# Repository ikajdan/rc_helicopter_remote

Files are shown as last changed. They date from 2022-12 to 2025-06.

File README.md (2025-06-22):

# RC Helicopter Remote

## Overview

This project is a custom PCB-based remote controller for an RC helicopter, built around the STM32L452RET6 microcontroller. It interfaces with two joysticks, four buttons, and two potentiometers to capture user input and transmits control data wirelessly via the NRF24L01 module to the helicopter's mainboard.

It complements the [Mainboard PCB](https://github.com/ikajdan/rc_helicopter_mainboard) and is developed in parallel with it as part of the same system.

## Features

The board features an STM32L452RET6 microcontroller, powered by a Li-Ion battery regulated to 3.3 V. It includes a 16 MHz crystal oscillator for accurate timing and clocking. Input devices such as two joysticks (X, Y, S), multiple buttons (SW1–SW4), and two analog potentiometers are connected directly to GPIO pins. Wireless communication is handled by the NRF24L01 module via SPI. Several status LEDs provide user feedback.

## PCB Design

This is a 2-layer compact PCB designed for handheld use, with easy access to controls and routing for digital and analog signals.

| Front View | Back View |
|---|---|
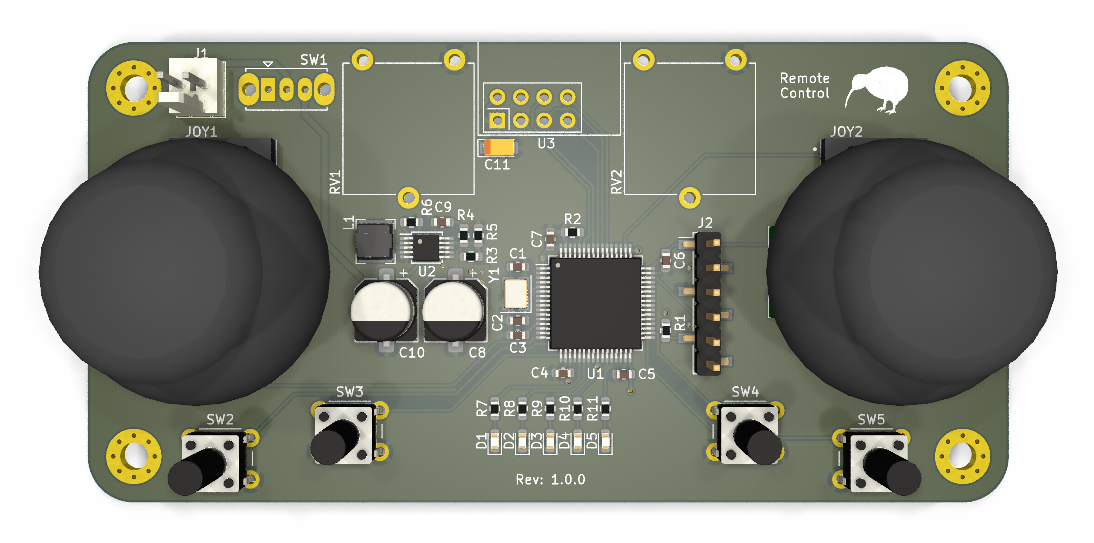
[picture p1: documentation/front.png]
PCB Front
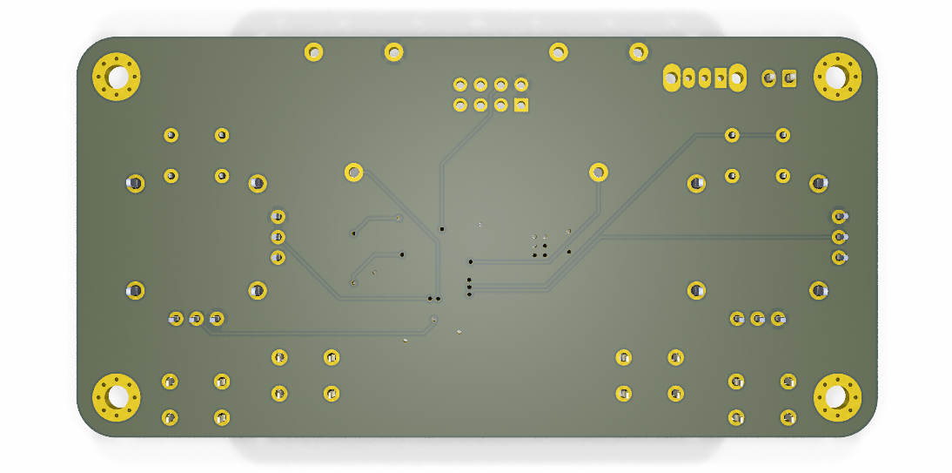
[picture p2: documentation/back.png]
PCB Back
|  |  |

## Power Supply

The power supply uses an LTC3440 buck-boost converter to step the battery voltage down to 3.3 V. Key components include a 10 µH inductor, 22 µF output capacitor, and feedback resistors (R3 = 340 kΩ, R5 = 200 kΩ, R4 = 15 kΩ) to set the output voltage. The converter is configured for efficient operation across a wide input range and includes filtering components for stability. A power switch and 10 µF input capacitor (C10) are included for basic input protection and noise reduction.

## License

This project is licensed under the [CERN Open Hardware Licence Version 2 - Permissive (CERN-OHL-P)](https://ohwr.org/cern_ohl_p_v2.txt).
You are free to use, modify, and distribute this design, provided you retain notices and disclaimers as specified in the license terms. See the [LICENSE](LICENSE.md) file for full details.

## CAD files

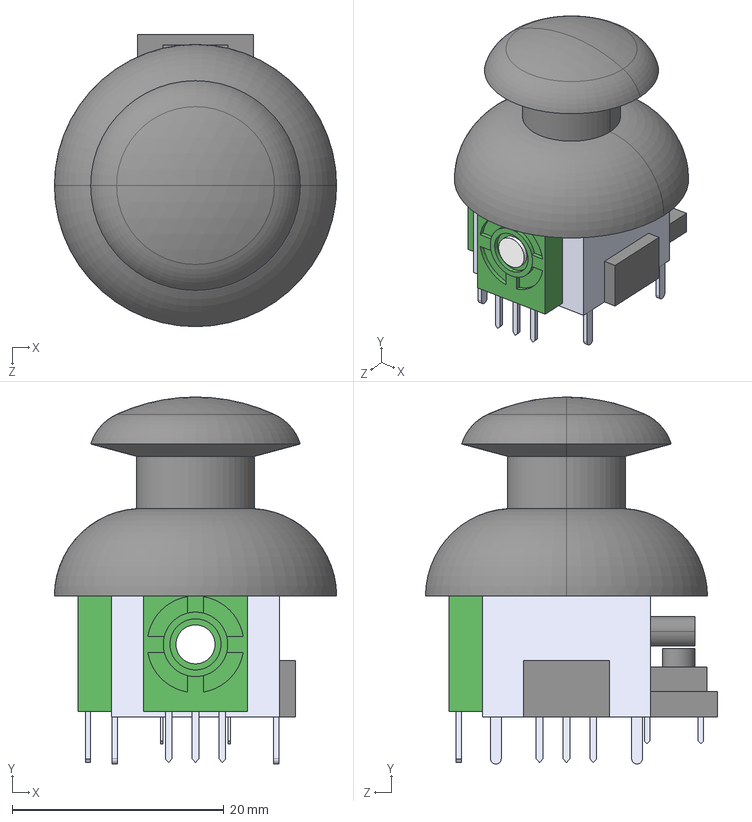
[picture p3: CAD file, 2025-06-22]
hardware/models/COM-09032.step
26.7 x 34.7 x 27.6 mm

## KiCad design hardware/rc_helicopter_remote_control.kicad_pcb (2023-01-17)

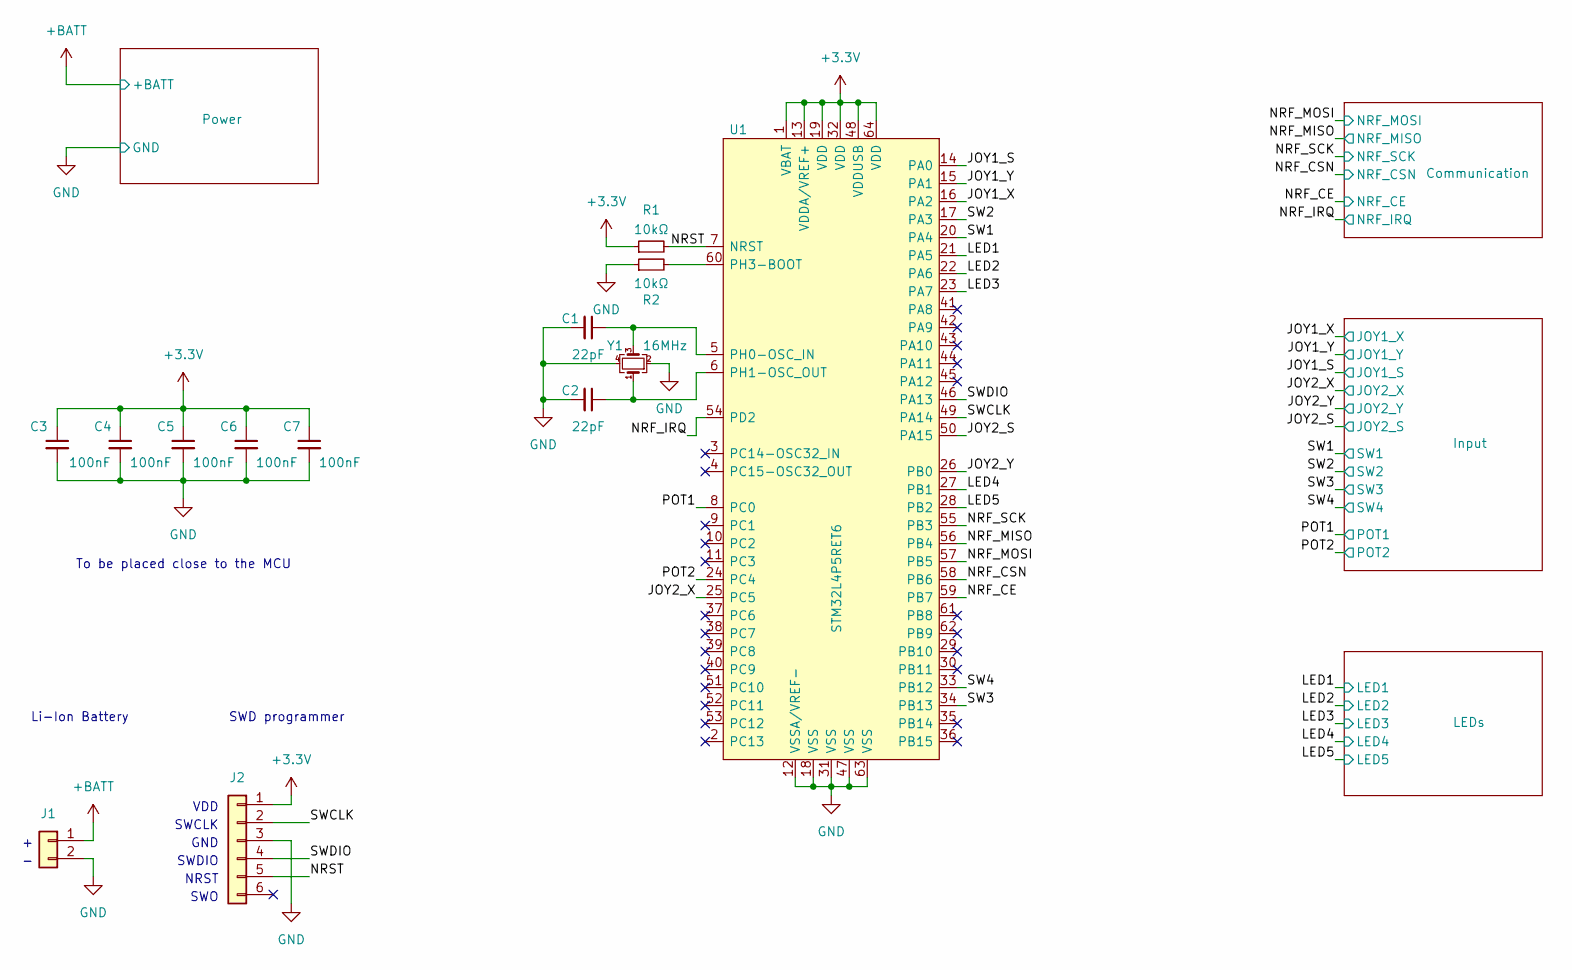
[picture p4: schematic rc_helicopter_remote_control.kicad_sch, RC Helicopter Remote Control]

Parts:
C1, C2: 22pF; C_0603_1608Metric
C3, C4, C5, C6, C7: 100nF; C_0603_1608Metric
J1: Battery Pack; Molex_KK-254_AE-6410-02A_1x02_P2.54mm_Vertical
J2: SWD; PinHeader_1x06_P2.54mm_Vertical_SMD_Pin1Left
R1, R2: 10kΩ; R_0603_1608Metric
U1: STM32L4P5RET6; LQFP-64_10x10mm_P0.5mm
Y1: 16MHz; Crystal_SMD_3225-4Pin_3.2x2.5mm

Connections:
+3.3V: C3.1, C4.1, C5.1, C6.1, C7.1, J2.1, R1.1, U1.1 (VBAT), U1.13 (VDDA/VREF+), U1.19 (VDD), U1.32 (VDD), U1.48 (VDDUSB), U1.64 (VDD); also elsewhere on the board
+BATT: J1.1; also elsewhere on the board
/JOY1_S: U1.14 (PA0); also elsewhere on the board
/JOY1_X: U1.16 (PA2); also elsewhere on the board
/JOY1_Y: U1.15 (PA1); also elsewhere on the board
/JOY2_S: U1.50 (PA15); also elsewhere on the board
/JOY2_X: U1.25 (PC5); also elsewhere on the board
/JOY2_Y: U1.26 (PB0); also elsewhere on the board
/LED1: U1.21 (PA5); also elsewhere on the board
/LED2: U1.22 (PA6); also elsewhere on the board
/LED3: U1.23 (PA7); also elsewhere on the board
/LED4: U1.27 (PB1); also elsewhere on the board
/LED5: U1.28 (PB2); also elsewhere on the board
/NRF_CE: U1.59 (PB7); also elsewhere on the board
/NRF_CSN: U1.58 (PB6); also elsewhere on the board
/NRF_IRQ: U1.54 (PD2); also elsewhere on the board
/NRF_MISO: U1.56 (PB4); also elsewhere on the board
/NRF_MOSI: U1.57 (PB5); also elsewhere on the board
/NRF_SCK: U1.55 (PB3); also elsewhere on the board
/NRST: J2.5, R1.2, U1.7 (NRST)
/POT1: U1.8 (PC0); also elsewhere on the board
/POT2: U1.24 (PC4); also elsewhere on the board
/SW1: U1.20 (PA4); also elsewhere on the board
/SW2: U1.17 (PA3); also elsewhere on the board
/SW3: U1.34 (PB13); also elsewhere on the board
/SW4: U1.33 (PB12); also elsewhere on the board
/SWCLK: J2.2, U1.49 (PA14)
/SWDIO: J2.4, U1.46 (PA13)
GND: C1.2, C2.2, C3.2, C4.2, C5.2, C6.2, C7.2, J1.2, J2.3, R2.1, U1.12 (VSSA/VREF-), U1.18 (VSS), U1.31 (VSS), U1.47 (VSS), U1.63 (VSS), Y1.2, Y1.4; also elsewhere on the board
unnamed: C1.1, U1.5 (PH0-OSC_IN), Y1.3
unnamed: C2.1, U1.6 (PH1-OSC_OUT), Y1.1
unnamed: R2.2, U1.60 (PH3-BOOT)

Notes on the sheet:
Li-Ion Battery
SWDIO
To be placed close to the MCU
NRST
VDD
SWD programmer
GND
SWCLK
SWO

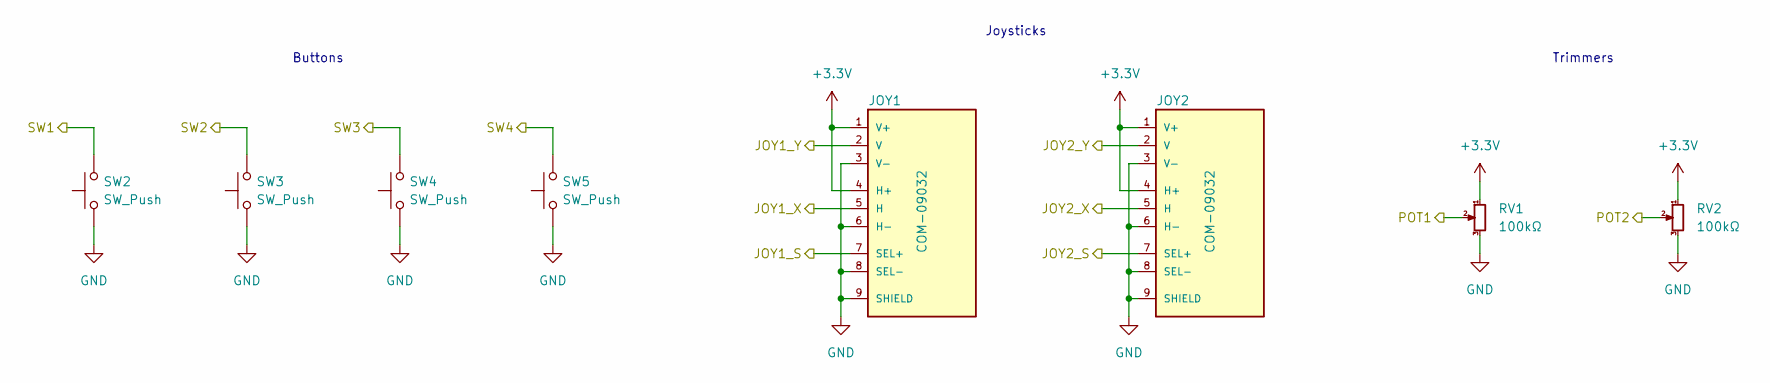
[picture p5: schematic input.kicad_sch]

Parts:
JOY1, JOY2: COM-09032; XDCR_COM-09032; PARTREV N/A
RV1, RV2: 100kΩ; Potentiometer_ACP_CA14V-15_Vertical
SW2, SW3, SW4, SW5: SW_Push; SW_PUSH_6mm_H13mm

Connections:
+3.3V: JOY1.1 (V+), JOY1.4 (H+), JOY2.1 (V+), JOY2.4 (H+), RV1.1, RV2.1; also elsewhere on the board
/JOY1_S: JOY1.7 (SEL+); also elsewhere on the board
/JOY1_X: JOY1.5 (H); also elsewhere on the board
/JOY1_Y: JOY1.2 (V); also elsewhere on the board
/JOY2_S: JOY2.7 (SEL+); also elsewhere on the board
/JOY2_X: JOY2.5 (H); also elsewhere on the board
/JOY2_Y: JOY2.2 (V); also elsewhere on the board
/POT1: RV1.2; also elsewhere on the board
/POT2: RV2.2; also elsewhere on the board
/SW1: SW2.1; also elsewhere on the board
/SW2: SW3.1; also elsewhere on the board
/SW3: SW4.1; also elsewhere on the board
/SW4: SW5.1; also elsewhere on the board
GND: JOY1.3 (V-), JOY1.6 (H-), JOY1.8 (SEL-), JOY1.9 (SHIELD), JOY2.3 (V-), JOY2.6 (H-), JOY2.8 (SEL-), JOY2.9 (SHIELD), RV1.3, RV2.3, SW2.2, SW3.2, SW4.2, SW5.2; also elsewhere on the board

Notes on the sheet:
Trimmers
Joysticks
Buttons

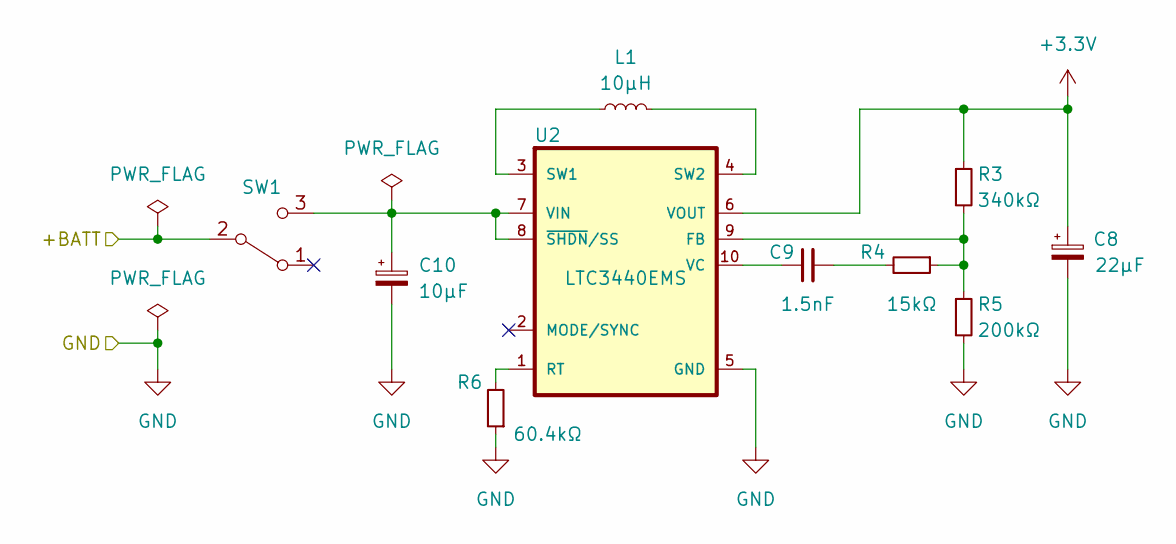
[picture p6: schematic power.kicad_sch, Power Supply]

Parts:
C8: 22μF; CP_Elec_6.3x5.4
C9: 1.5nF; C_0603_1608Metric
C10: 10μF; CP_Elec_6.3x5.4
L1: 10μH; L_Bourns-SRN4018
R3: 340kΩ; R_0603_1608Metric
R4: 15kΩ; R_0603_1608Metric
R5: 200kΩ; R_0603_1608Metric
R6: 60.4kΩ; R_0603_1608Metric
SW1: SW_SPST; SW_Slide_1P2T_CK_OS102011MS2Q
U2: LTC3440EMS; MSOP-10_3x3mm_P0.5mm; MPN LTC3440EMS#PBF

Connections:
+3.3V: C8.1, R3.1, U2.6 (VOUT); also elsewhere on the board
+BATT: SW1.2 (B); also elsewhere on the board
GND: C8.2, C10.2, R5.2, R6.1, U2.5 (GND); also elsewhere on the board
unnamed: C9.1, U2.10 (VC)
unnamed: C9.2, R4.2
unnamed: C10.1, SW1.3 (C), U2.7 (VIN), U2.8 (~SHDN/SS)
unnamed: L1.1, U2.3 (SW1)
unnamed: L1.2, U2.4 (SW2)
unnamed: R3.2, R4.1, R5.1, U2.9 (FB)
unnamed: R6.2, U2.1 (RT)

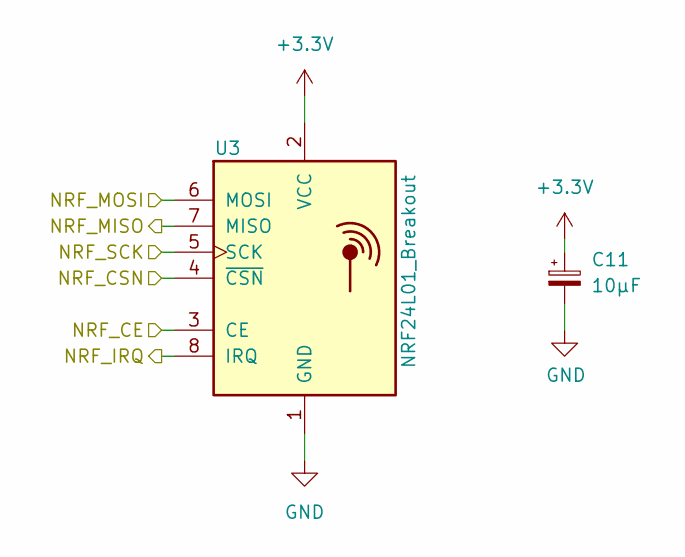
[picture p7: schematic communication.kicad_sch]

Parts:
C11: 10μF; CP_EIA-3216-10_Kemet-I
U3: NRF24L01_Breakout; nRF24L01_Breakout

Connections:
+3.3V: C11.1, U3.2 (VCC); also elsewhere on the board
/NRF_CE: U3.3 (CE); also elsewhere on the board
/NRF_CSN: U3.4 (~CSN); also elsewhere on the board
/NRF_IRQ: U3.8 (IRQ); also elsewhere on the board
/NRF_MISO: U3.7 (MISO); also elsewhere on the board
/NRF_MOSI: U3.6 (MOSI); also elsewhere on the board
/NRF_SCK: U3.5 (SCK); also elsewhere on the board
GND: C11.2, U3.1 (GND); also elsewhere on the board

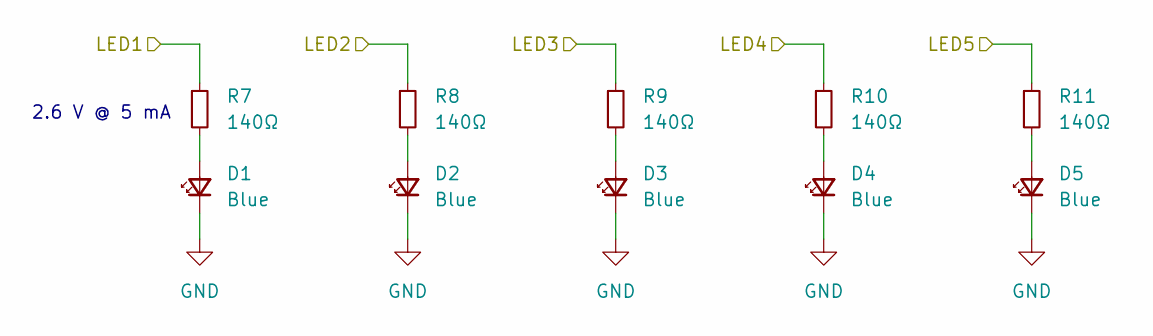
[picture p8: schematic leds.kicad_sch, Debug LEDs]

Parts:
D1, D2, D3, D4, D5: Blue; LED_0603_1608Metric
R7, R8, R9, R10, R11: 140Ω; R_0603_1608Metric

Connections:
/LED1: R7.1; also elsewhere on the board
/LED2: R8.1; also elsewhere on the board
/LED3: R9.1; also elsewhere on the board
/LED4: R10.1; also elsewhere on the board
/LED5: R11.1; also elsewhere on the board
GND: D1.1 (K), D2.1 (K), D3.1 (K), D4.1 (K), D5.1 (K); also elsewhere on the board
unnamed: D1.2 (A), R7.2
unnamed: D2.2 (A), R8.2
unnamed: D3.2 (A), R9.2
unnamed: D4.2 (A), R10.2
unnamed: D5.2 (A), R11.2

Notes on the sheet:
2.6 V @ 5 mA

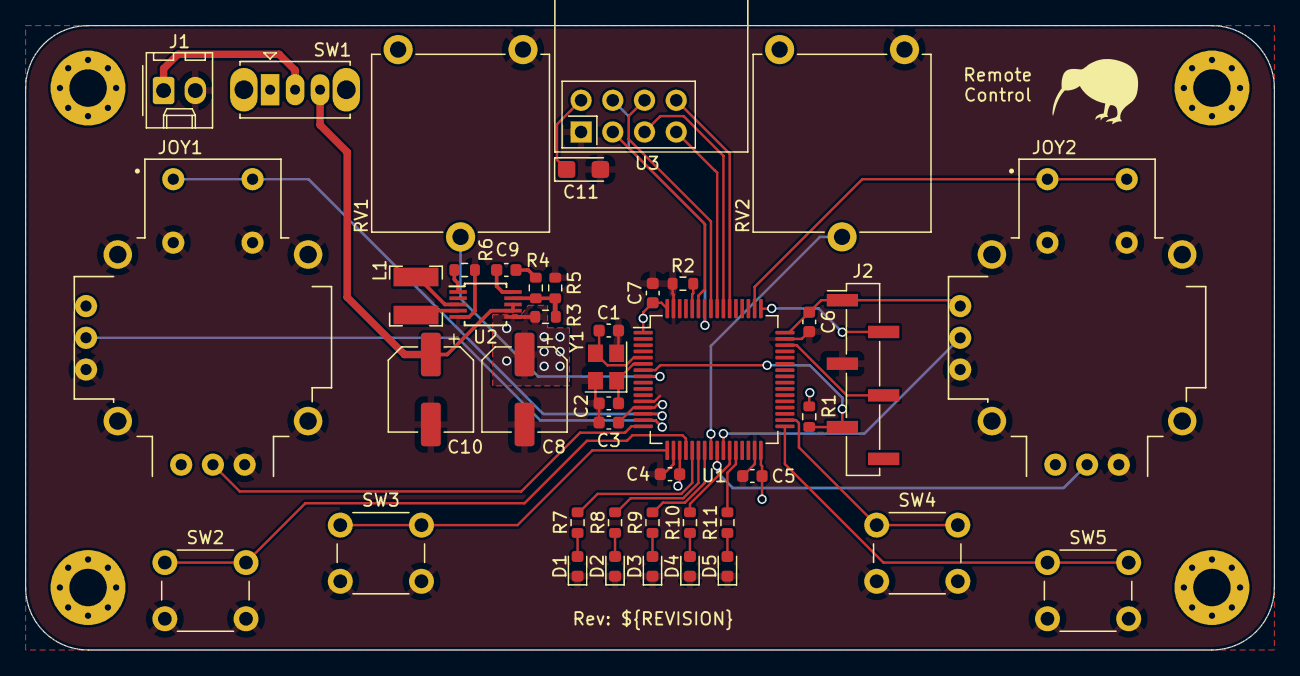
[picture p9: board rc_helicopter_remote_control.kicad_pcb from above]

Board: 2 copper layers, 100.0 x 50.0 mm, 43 parts (0 on the bottom side), 44 nets.

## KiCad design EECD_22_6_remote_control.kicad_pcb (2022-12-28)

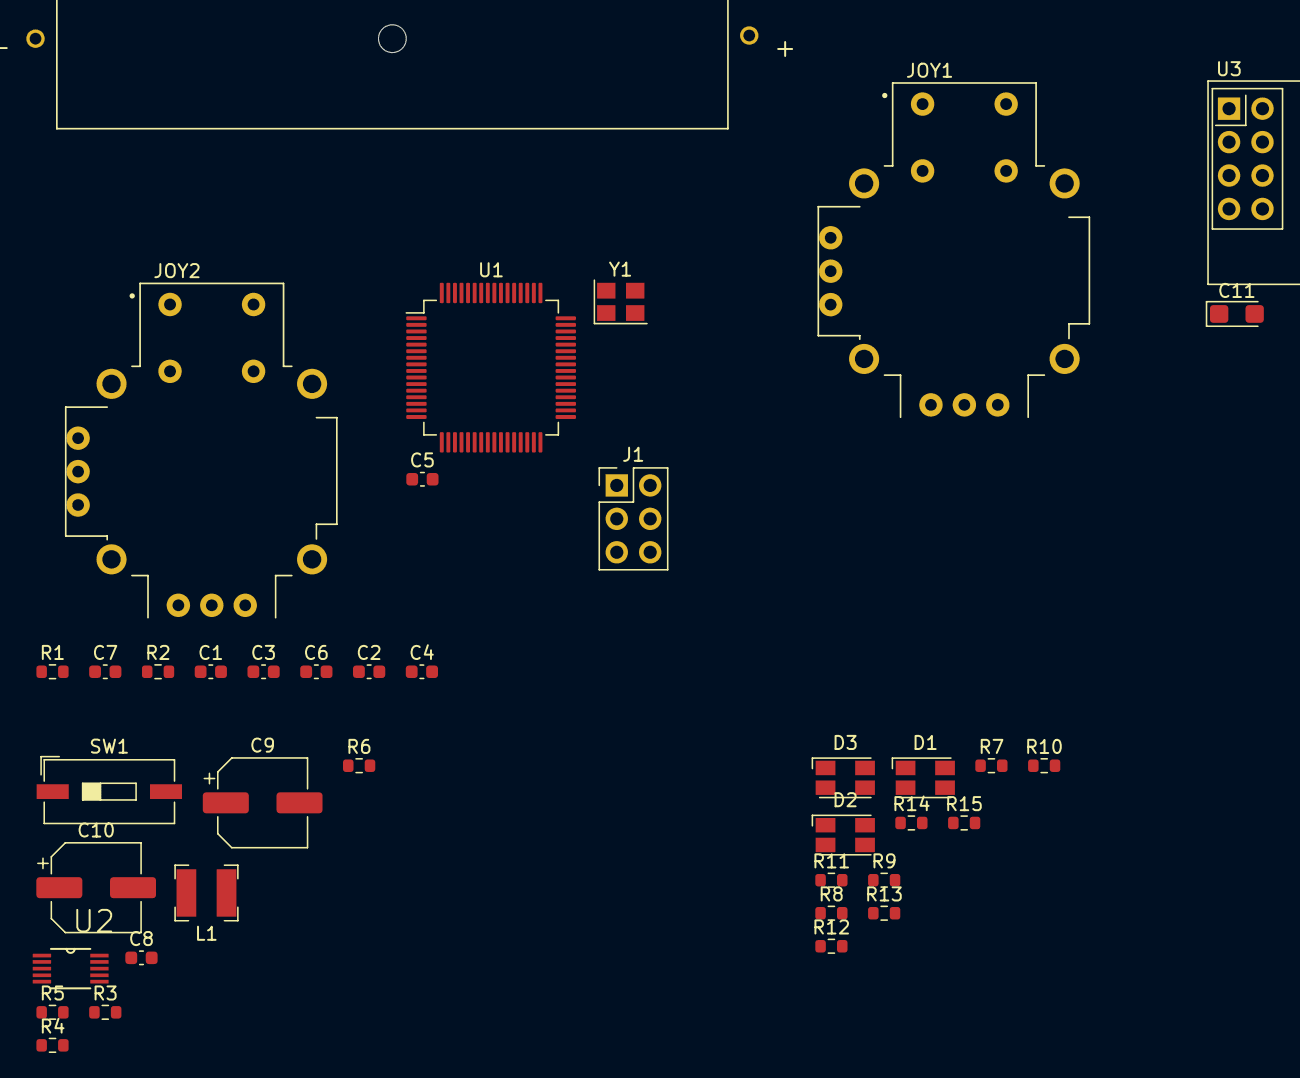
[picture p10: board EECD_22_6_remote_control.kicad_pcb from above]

Board: 2 copper layers, 39 parts (0 on the bottom side), 47 nets, no tracks yet.

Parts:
BT1: Li-Ion; BAT_BCAAAW
C1, C2: 22pF; C_0603_1608Metric
C3, C4, C5, C6, C7: 100nF; C_0603_1608Metric
C8: 1.5nF; C_0603_1608Metric
C9: 22μF; CP_Elec_6.3x5.4
C10: 10μF; CP_Elec_6.3x5.4
C11: 10μF; CP_EIA-3216-10_Kemet-I
D1, D2, D3: LED_RGBK; LED_Avago_PLCC4_3.2x2.8mm_CW
J1: SWD; PinHeader_2x03_P2.54mm_Vertical
JOY1, JOY2: COM-09032; XDCR_COM-09032
L1: 10μH; L_Bourns-SRN4018
R1, R2: 10kΩ; R_0603_1608Metric
R3: 340kΩ; R_0603_1608Metric
R4: 15kΩ; R_0603_1608Metric
R5: 60.4kΩ; R_0603_1608Metric
R6: 200kΩ; R_0603_1608Metric
R7, R8, R9: 180Ω; R_0603_1608Metric
R10, R11, R12, R13, R14, R15: 100Ω; R_0603_1608Metric
SW1: SW_SPST; SW_DIP_SPSTx01_Slide_9.78x4.72mm_W8.61mm_P2.54mm
U1: STM32L4P5RET6; LQFP-64_10x10mm_P0.5mm
U2: LTC3440EMS; SOP50P490X110-10N
U3: NRF24L01_Breakout; nRF24L01_Breakout
Y1: 16MHz; Crystal_SMD_3225-4Pin_3.2x2.5mm

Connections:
+3.3V: C3.1, C4.1, C5.1, C6.1, C7.1, C9.2, C11.1, D1.4 (K), D2.4 (K), D3.4 (K), J1.1, JOY1.H1 (H+), JOY1.V1 (V+), JOY2.H1 (H+), JOY2.V1 (V+), R1.1, R3.1, U1.1 (VBAT), U1.13 (VDDA/VREF+), U1.19 (VDD), U1.32 (VDD), U1.48 (VDDUSB), U1.64 (VDD), U2.6 (VOUT), U3.2 (VCC)
+BATT: BT1.1 (+), SW1.1 (A)
/JOY1_S: JOY1.B1A (SEL+), U1.16 (PA2)
/JOY1_X: JOY1.H2 (H), U1.15 (PA1)
/JOY1_Y: JOY1.V2 (V), U1.14 (PA0)
/JOY2_S: JOY2.B1A (SEL+), U1.44 (PA11)
/JOY2_X: JOY2.H2 (H), U1.43 (PA10)
/JOY2_Y: JOY2.V2 (V), U1.42 (PA9)
/LED1_B: R13.2, U1.62 (PB9)
/LED1_G: R10.2, U1.61 (PB8)
/LED1_R: R7.2, U1.59 (PB7)
/LED2_B: R14.2, U1.33 (PB12)
/LED2_G: R11.2, U1.30 (PB11)
/LED2_R: R8.2, U1.29 (PB10)
/LED3_B: R15.2, U1.36 (PB15)
/LED3_G: R12.2, U1.35 (PB14)
/LED3_R: R9.2, U1.34 (PB13)
/NRF_CE: U1.26 (PB0), U3.3 (CE)
/NRF_CSN: U1.20 (PA4), U3.4 (~CSN)
/NRF_IRQ: U1.41 (PA8), U3.8 (IRQ)
/NRF_MISO: U1.22 (PA6), U3.7 (MISO)
/NRF_MOSI: U1.23 (PA7), U3.6 (MOSI)
/NRF_SCK: U1.21 (PA5), U3.5 (SCK)
/NRST: J1.5, R1.2, U1.7 (NRST)
/Power/FB: R3.2, R4.1, R6.1, U2.9 (FB)
/SWCLK: J1.2, U1.49 (PA14)
/SWDIO: J1.4, U1.46 (PA13)
/SWO: J1.6, U1.55 (PB3)
GND: BT1.2 (-), C1.2, C2.2, C3.2, C4.2, C5.2, C6.2, C7.2, C9.1, C10.2, C11.2, J1.3, JOY1.B2A (SEL-), JOY1.H3 (H-), JOY1.S1 (SHIELD), JOY1.S2 (SHIELD), JOY1.S3 (SHIELD), JOY1.S4 (SHIELD), JOY1.V3 (V-), JOY2.B2A (SEL-), JOY2.H3 (H-), JOY2.S1 (SHIELD), JOY2.S2 (SHIELD), JOY2.S3 (SHIELD), JOY2.S4 (SHIELD), JOY2.V3 (V-), R2.1, R5.2, R6.2, U1.12 (VSSA/VREF-), U1.18 (VSS), U1.31 (VSS), U1.47 (VSS), U1.63 (VSS), U2.5 (GND), U3.1 (GND), Y1.2, Y1.4
unnamed: C1.1, U1.5 (PH0-OSC_IN), Y1.3
unnamed: C2.1, U1.6 (PH1-OSC_OUT), Y1.1
unnamed: C8.1, U2.10 (VC)
unnamed: C8.2, R4.2
unnamed: C10.1, SW1.2 (B), U2.7 (VIN), U2.8 (~SHDN/SS)
unnamed: D1.1 (RA), R7.1
unnamed: D1.2 (GA), R10.1
unnamed: D1.3 (BA), R13.1
unnamed: D2.1 (RA), R8.1
unnamed: D2.2 (GA), R11.1
unnamed: D2.3 (BA), R14.1
unnamed: D3.1 (RA), R9.1
unnamed: D3.2 (GA), R12.1
unnamed: D3.3 (BA), R15.1
unnamed: L1.1, U2.3 (SW1)
unnamed: L1.2, U2.4 (SW2)
unnamed: R2.2, U1.60 (PH3-BOOT)
unnamed: R5.1, U2.1 (RT)

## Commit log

2022-11-22 you can understand at least smth now
    [EECD_22_6_remote_control.kicad_sch]
2022-12-20 normal power supply + footprints
    [EECD_22_6_remote_control.kicad_pcb, EECD_22_6_remote_control.kicad_sch]
2022-12-28 Move project files to the top directory
    [EECD_22_6_remote_control.kicad_pcb, EECD_22_6_remote_control.kicad_sch]
2022-12-28 Apply custom drawing sheet and project settings
    [EECD_22_6_remote_control.kicad_pcb, EECD_22_6_remote_control.kicad_sch]
2022-12-28 Schematic refactor
    - Divide the schematic into hierarchical sheets
    - Fix ERCs
    - Remove unused footprints
    - Add SWD connector
    - Add bypass capacitors
    [EECD_22_6_remote_control.kicad_pcb, EECD_22_6_remote_control.kicad_sch, communication.kicad_sch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]
2022-12-28 Use proper footprints for custom symbols
    [COM-09032.step, EECD_22_6_remote_control.kicad_pcb, EECD_22_6_remote_control.kicad_sch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]
2022-12-28 Rename the project
    [rc_helicopter_remote_control.kicad_pcb, rc_helicopter_remote_control.kicad_sch]
2022-12-29 Improve DCDC converter diagram
    [communication.kicad_sch, leds.kicad_sch, power.kicad_sch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]
2022-12-29 Replace RGB leds with single color ones
    [communication.kicad_sch, leds.kicad_sch, power.kicad_sch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]
2022-12-29 Add buttons and trimmers
    [communication.kicad_sch, input.kicad_sch, leds.kicad_sch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]
2022-12-29 Arrange footprints
    [communication.kicad_sch, input.kicad_sch, leds.kicad_sch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]
2022-12-30 Use more appropriate MCU pins for peripherals
    [input.kicad_sch, leds.kicad_sch, power.kicad_sch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]
2023-01-09 Route PCB tracks
    [input.kicad_sch, rc_helicopter_remote_control.kicad_pcb]
2023-01-10 Improve the routing
    [communication.kicad_sch, input.kicad_sch, leds.kicad_sch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]
2023-01-17 Release v1.0.0
    [rc_helicopter_remote_control.kicad_pcb, rc_helicopter_remote_control.kicad_sch]
2025-06-22 Refactor the project
    [COM-09032.step, communication.kicad_sch, input.kicad_sch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]
